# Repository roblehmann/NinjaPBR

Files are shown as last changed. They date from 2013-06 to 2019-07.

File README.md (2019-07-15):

# NinjaPBR - The Photobioreactor for Cyanobacteria and Microalgae

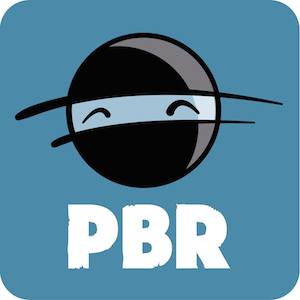
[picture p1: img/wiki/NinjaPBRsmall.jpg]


NinjaPBR is an opensource (GPLv3) photobioreactor implementation to study the growth of cyanobacteria and microalgae in liquid cultures. It allows the online measurement of the number of cells under various environmental conditions.

The firmware for the Arduino-based controller is located in this repository. The corresponding laser cutting templates and controller board Fritzing schematics are also provided here. The python-based graphical user interface can be found [here](https://github.com/roblehmann/pyNinjaPBR).

Want to learn more? See the [wiki](https://github.com/roblehmann/NinjaPBR/wiki).

## Motivation
One application of the NinjaPBR is the understanding of how cyanobacteria tell time. Some cyanobacterial strains predict the natural procession of light and dark phases during each day with an internal molecular clock consisting of the KaiA, B and C proteins. This clock evolved to accommodate the day length on earth of approximately 24h and can adapt to varying relative lengths of light and dark (LD) phases. The NinjaPBR allows the simulation of different day lengths, light and dark phase lengths, and also light brightness profiles over the subjective day. The observation of growth rates under extreme LD rhythms could indicate the limits of adaptibility of the circadian clock mechanism.

The central measured variable, the number of cells in the liquid culture, is measured as usual by the attenuation of incident light on its path through the solution (optical density, OD). In short, NinjaPBR

*  is an open-source, cost-effective, easy to assemble cultivation system
*  allows precise turbidity measurement using infrared light
*  can be easily extended to measure other parameters, e.g., O<sub>2</sub> and CO<sub>2</sub> in the off-gas
*  allows cultivation in batch, fed-batch, and chemostat mode
*  allows easy changes in illumination spectra by varying LEDs
*  is prepared for optional measurement of additional wavelengths to assess physiological parameters, e.g. pigment content

The NinjaPBR is designed to use a single controller box to control multiple Sample Pods, each hosting a separate culture vessel within a water bath. Accordingly, each pod requires a full set of sensors for each parameter, an illumination light source, and gas supply.

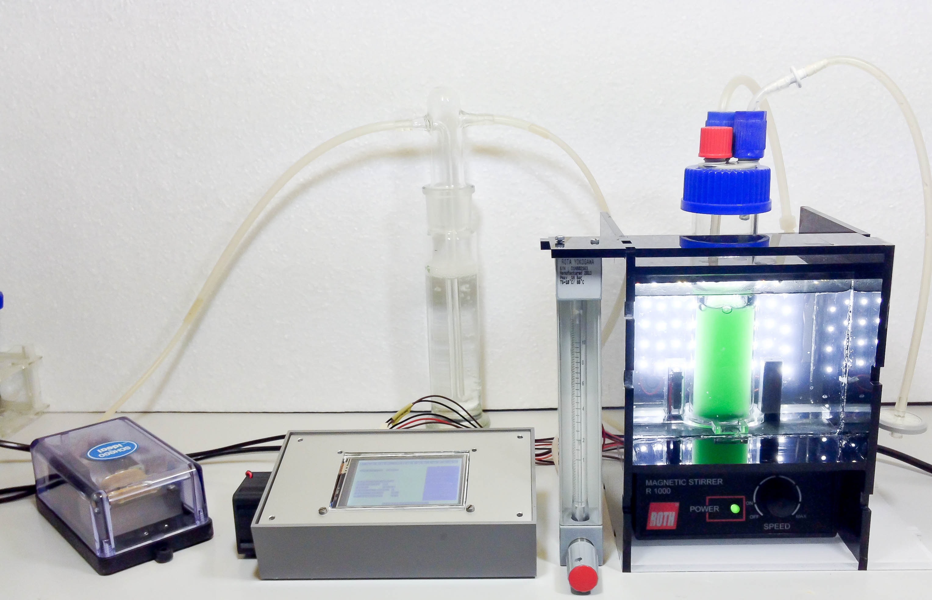
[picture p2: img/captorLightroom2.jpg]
Setup


*  Measure cell count via attenuation (OD, div. λ, calibration needed)
*  Temperature measured in water bath around vessel
*  Operation Modes: Batch, Fed Batch, Chemostat, (Turbidostat)
*  Compact – each Pod 205x140x150mm
*  Small sample volume < 120ml
*  Modular – 3 sample pods for 1 controller
*  Light programs for LED light source
*  Arduino-based controller for reactor management and data logging
*  Data transfer and control by computer GUI via USB

# Preliminary Experiments

### Batch Experiment with light/dark cycles
 The figure below shows the result of the following preliminary experiment:
 
*  Minimal reactor setup with Synechococcus sp. PCC 7002 in optimized media
*  Room temperature 24.5 °C, no temperature control
*  PFD 60 μmol m<sup>-2</sup>s<sup>-1</sup>
*  12/12h LD cycle using white LED light
*  Turbidity measured using 850nm wavelength
*  Reference measurement before experiment start with media-filled cuvette
*  sampling frequency F<sub>samp</sub> = 1/5 min<sup>-1</sup>
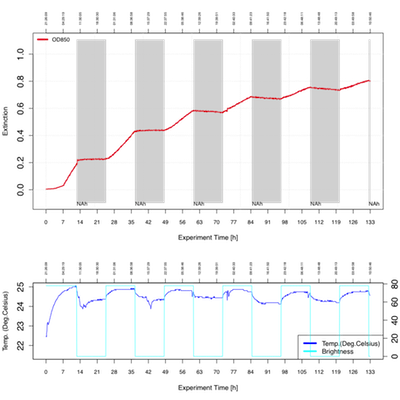
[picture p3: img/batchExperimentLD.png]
LD Batch Run


### Chemostat Experiment - Continuous dilution of culture with fresh media

*  Growth rate adjusts to dilution rate, yielding steady state in cell number
*  Experiment duration drastically extended up to months
*  Required extension of minimal setup:
	- Peristaltic pump attached to third reactor vessel port
	- Superfluous media due to dilution is removed via the off-gas vent via glass tube, which is placed at fixed height inside reactor vessel
* Experimental data with this setup are shown below
	-  Synechocystis sp. PCC 6803
	-  various LD rhythms
	-  Multiple wavelength OD measurement

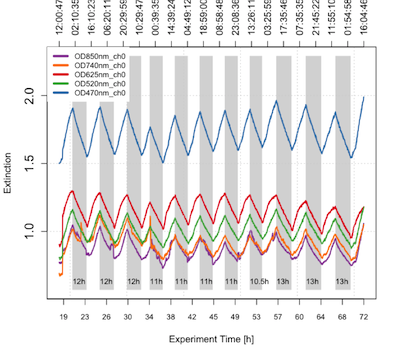
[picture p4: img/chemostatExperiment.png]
Chemostat Run


---
# Inspiration

There are already a range of great bioreactor and photobioreactor designs out there, here is a small selection. In addition, there are several other great instruments on github, such as the [NinjaPCR](https://github.com/hisashin/NinjaPCR) open source Thermocycler or a [plate reader](https://github.com/csbl/platereader).

### Synechocystis Physiological Parameters
A small part pf the extensive [contribution](http://2015.igem.org/Team:Amsterdam/Project/Phy_param/Synechocysytis) of team Amsterdam to the international Genetically Engineered Machine Competition iGEM 2015 consisted of the extension of a commercial PBR allowing its operation as turbidostat. This project involved the University of Amsterdam, the Free University of Amsterdam, the Swammerdam Institute for Life Sciences (SILS), and several other institutions.

### Biomonstaaar
The photobioreactor design called Biomonstaaar was developed as a part of the  SpaceGAMBIT program. It is documented on [SpaceGAMBIT](http://www.spacegambit.org/biomonstaaar-open-source-bioreactor/) and on [Instructables](http://www.instructables.com/id/Biomonstaaar/). The concept is to build an array of three photobioreactors, each of which is controlled by an Arduino. The resulting data are collected in a Raspberry Pi and then uploaded into the cloud.

### Bertha
The Bertha bioreactor project of the École polytechnique fédérale de Lausanne (EPFL) employs many useful technologies, such as ZigBee Bluetooth modules for wireless data transfer. The code as well as physical designs are provided on [github](https://github.com/Bioreactor/Code-Bioreactor).

---
# Instructions

### Pod Construction

* Sample pod built from 5mm thick PMMA sheet material
* 2D templates for laser cutting are provided as EPS files in the templates sub-folder
	- Order cutting online from e.g. www.formulor.de, www.ponoko.com
	- Or manufacture yourself (maker lab / own laser cutter)
*  Minimal number of required bonding connections
*  Standard 10mm polystyrene cuvettes additionally required for light source / detector housing
*  Adhesive required for assembly
*  Check the [Wiki](https://github.com/roblehmann/NinjaPBR/wiki/Pod-Assembly) for more details and images

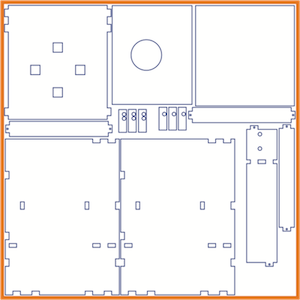
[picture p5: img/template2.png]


### Controller Based on Arduino

*  Arduino Mega + 3.2’’ touch screen with SD card slot
*  Breakout board for connection of periphery to Arduino provided as Fritzing sketch in the controller sub-folder
*  No expert knowledge in electronics required
*  Parts readily available 
*  Basic breakout board with 12V LED driver for all sample pods, and max. 2 emitter types on stripboard shown below
*  Controller puts out 12V for emitter, requiring separate driver ICs or current limiting resistors for each LED connection

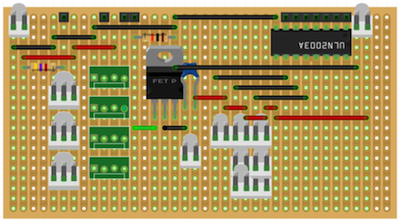
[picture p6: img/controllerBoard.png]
Controller Board


### Measurement of Cell Density

*  Standard attenuation measurement, comparable to benchtop spectrophotometer
*  Through culture vessel, yielding 40mm optical path
*  850nm high power Led with constant current source for highly constant output
*  No lenses required
*  Calibration curve of extinction to cell number required
*  Extension prepared to use side-scattering to increase linear range and decrease dependency on cell morphology
*  [Wiki](https://github.com/roblehmann/NinjaPBR/wiki/Measuring-Cell-Number) for more

### Python GUI

*  Download and display data from controller
*  Online display when continuously connected
*  Data logging
*  Up- / download scripted light programs
*  Scheduled reactor mode change (planned experiment start)
*  Easy GUI customization using wxGlade
*  [The Repository](https://github.com/roblehmann/pyNinjaPBR)

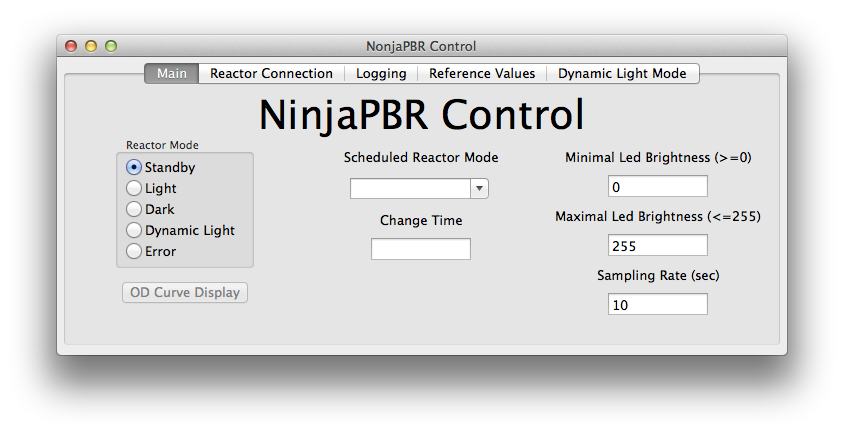
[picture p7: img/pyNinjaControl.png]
Frist Experiment


---
# Contribute to NinjaPBR!

Im looking for people who are interested in helping develop the NinjaPBR or apply it.

---
# Author
[Robert Lehmann](https://github.com/roblehmann)

Check out [Celldeg.com](http://celldeg.com/) if you are interested in ultra-high density cultivation of cyanobacteria

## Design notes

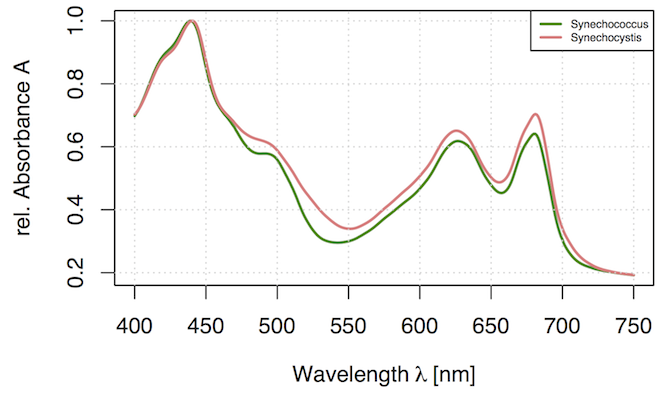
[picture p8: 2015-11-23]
img/wiki/od/cyano_absorbance_spectra.png

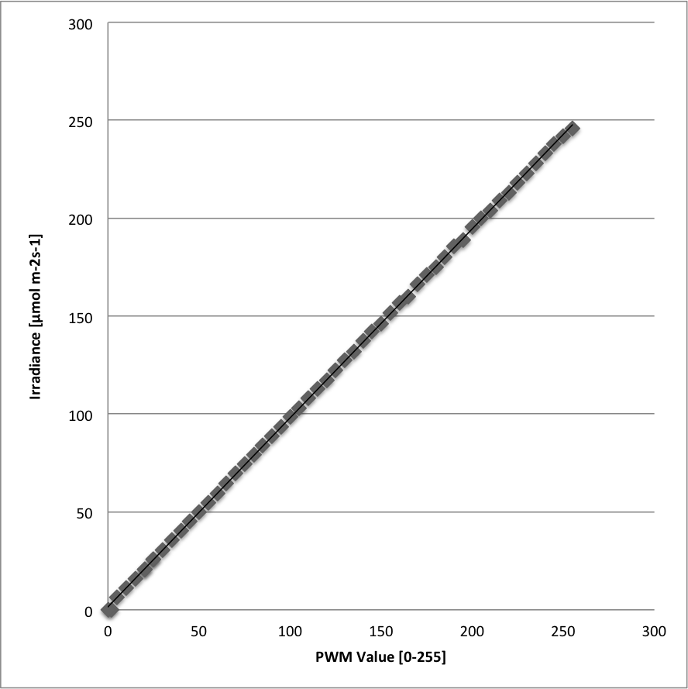
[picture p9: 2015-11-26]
img/wiki/controller/lightIntensity.png

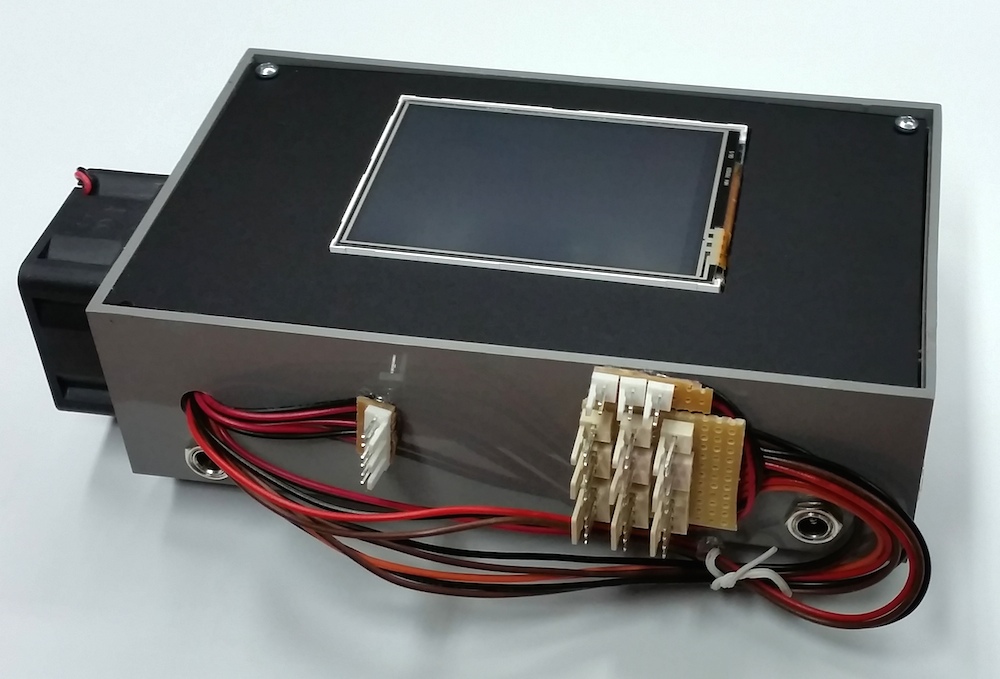
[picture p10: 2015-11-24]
img/wiki/controller/controller3.jpg

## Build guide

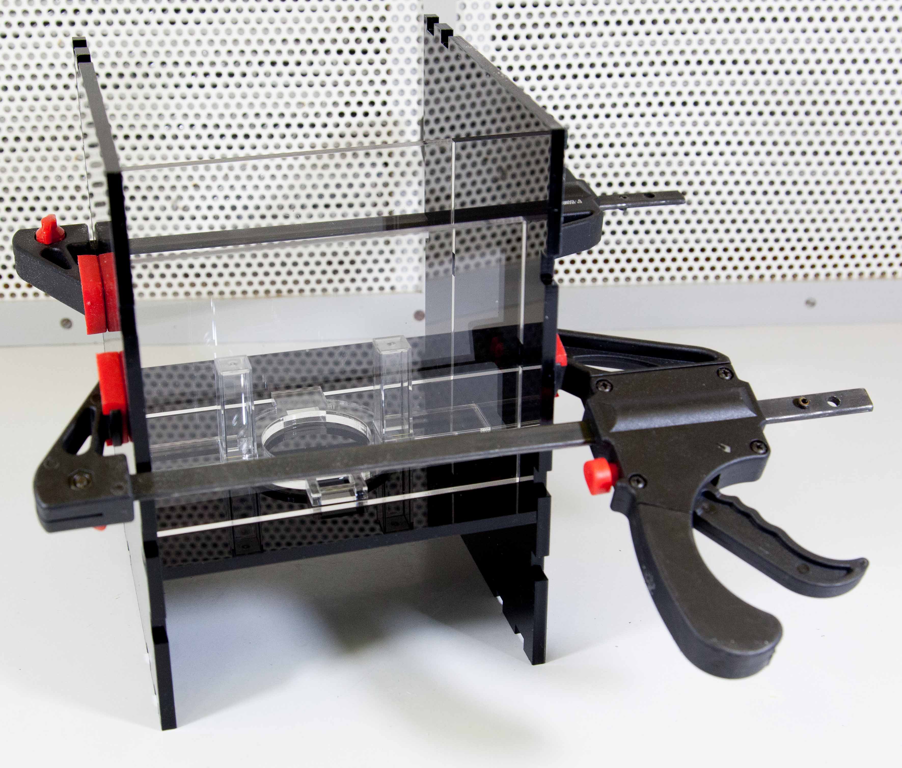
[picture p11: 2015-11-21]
img/wiki/assembly/step5.jpg

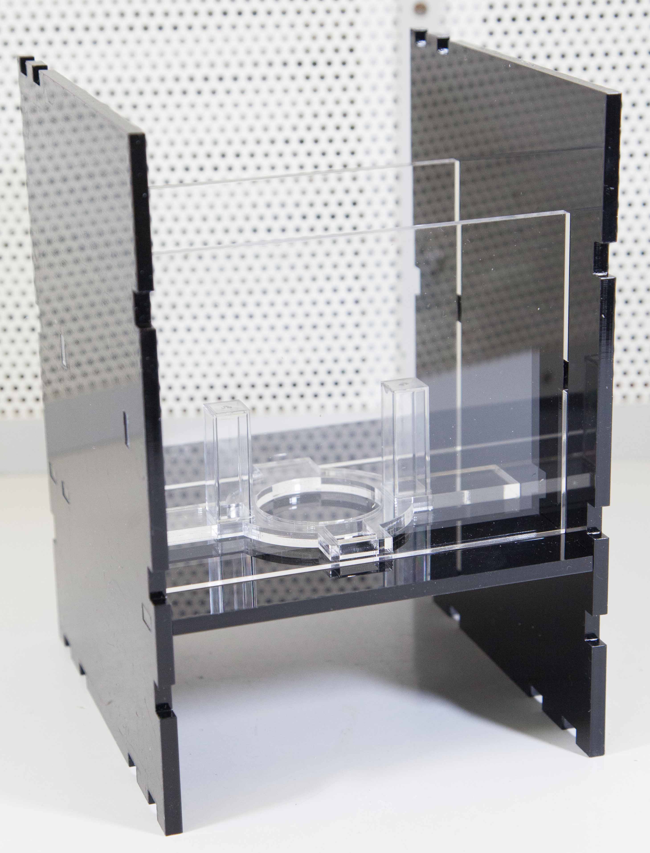
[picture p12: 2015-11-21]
img/wiki/assembly/step6.jpg

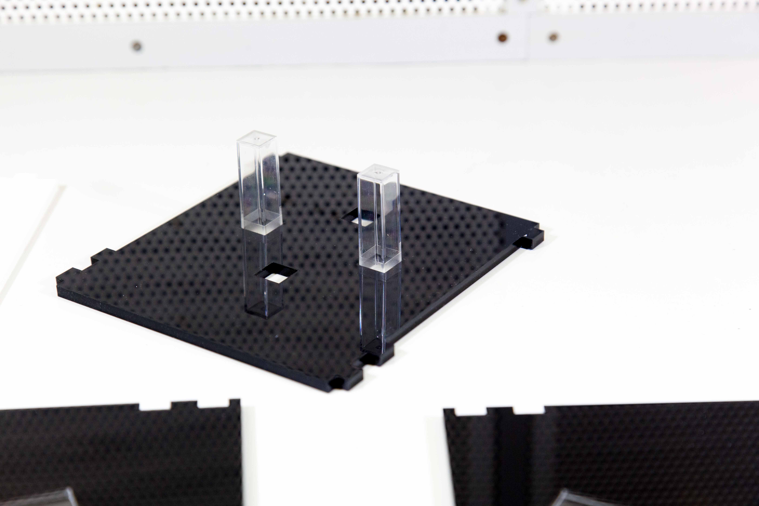
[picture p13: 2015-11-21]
img/wiki/assembly/step1a.jpg

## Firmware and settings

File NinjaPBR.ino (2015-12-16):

/*-------------------------
// NinjaPBR
// Arduino-based Photobioreactor for the cultivation of cyanobacteria and microalgae
//
// Author: r.lehmann@biologie.hu-berlin.de
-------------------------*/

#include <OneWire.h>
#include <DallasTemperature.h>
#include <Timer.h>
#include <Wire.h>
#include <TSL2561_mod.h>
#include <DS3232RTC.h>
#include <Time.h>
#include <UTFT.h>
#include <UTouch.h>
#include <UTFT_Buttons.h>
#include <SPI.h>
#include <SdFat.h>

//----------CONSTANTS-GLOBAL--------- //
#define BIOREACTOR_STANDBY_MODE   0   // nothing on, nothing measured
#define BIOREACTOR_LIGHT_MODE     1   // light const. at full brightness, od/temp. measured
#define BIOREACTOR_DARK_MODE      2   // light off, od/temp. measured
#define BIOREACTOR_DYNAMIC_MODE   3   // light varies according to uploaded dynamic profile, od/temp. measured
#define BIOREACTOR_ERROR_MODE     4   // something went wrong,switch off everything

//----------CONSTANTS-LIGHT--------- //
//#define  ledPin     13  // LED panel connected to digital pin 3
const int lightPins[] = {11,12,13};

#define MAX_LIGHT     0   // set illumination to specified max
#define MIN_LIGHT     1   // set illumination to specified min

//----------CONSTANTS- EMITTER --------- //
#define numLeds 1     // number of emitters with different wavelength
// number of culture chambers with individual OD sensors
// needs to match the number of OD sensor pins per type
const int ledPins[] = {8, 10};

//----------Number of Pods --------- //
#define numChambers 3

//----------CONSTANTS-GAS--------- //
#define  airValvePin 9
//----------CONSTANTS-MEDIUM--------- //
#define  mediumPumpPin 6

// marks default state of timer
#define timerNotSet -1

//----------CONSTANTS-TEMPERATURE--------- //
#define TEMPERATURE_SENSOR_PIN  19   // culture temperature

//----------TIMER DECLARATION--------- //
Timer t;

//----------GLOBAL VARIABLES--------- //
//global variables used by functions and are set by GUI
byte BIOREACTOR_MODE = BIOREACTOR_STANDBY_MODE;
byte bioreactorAncientMode = BIOREACTOR_STANDBY_MODE;

// LIGHT REGULATION //
byte minLightBrightness[3] = {0};
byte maxLightBrightness[3] = {255, 255, 255};

byte lightBrightness[3] = {0};       // holds brightness of LED panel in range 0-255 (0=off)

// Light profile //
const int      lightProfileLength = 200;
byte           brightnessValue[3][lightProfileLength];
unsigned long  brightnessDuration[3][lightProfileLength];
int            lightProfileIdx[3] = {0}; // indicates the current position in the light profile 

// Turbidostat Mode //
// if active, reactor checks of optical density exceeds "upperOdThr". if so, a
// series of dilution steps of length dilutionDuration are issued, until the OD
// is found below "lowerOdThr"
boolean  inTurbidostat    = false;   // is turbidostat mode is active
boolean  inDilution       = false;   // is turbidostat mode is active
int      dilutionDuration = 1;       // how long the medium pump should run to dilute one step (sec)
float    upperOdThr       = 1;       // when to start diluting
float    lowerOdThr       = .8;      // when to stop diluting

// OD MEASUREMENTS //
// array storing the resulting OD values for logging
// column 5 stores background values, column 0-4 the background-corrected OD values
float odValues[numChambers][ 6 ] = {0};

//reference values for OD calculation
// column 5 stores background values, column 0-4 the background-corrected reference intensity values
float refValues[numChambers][ 6 ] = {65535, 65535, 65535, 65535, 65535, 65535};

// emitter-specific brightness value. 
// adjust this value to optimize for individual geometry
// set to 100 for integration time 2 and sfh4550
float emitterBrightness[ 5 ] = {100,162,255,255,255};

// state flag, determining whether to measure reference value for OD calculation or OD values
boolean readReferenceValues = false;
//flag indicating if reference values were read already
String referenceValuesDone = "";

// AIR PUMP REGULATION //
boolean airPumpState;

// how often to measure od/temp
unsigned long sensorSamplingTime = 5L; //seconds

// store timer IDs, to be able to remove them when the BIOREACTOR_MODE or the sample timer change
int lightChangeTimerID[] = {-1, -1, -1};
int sensorReadTimerID = -1;

float temperatureInLiquid[3] = {0, 0, 0};

String inputString = "";         // a string to hold incoming data
boolean stringComplete = false;  // whether the string is complete
// for logging and communication
const char* sep = ",";
String sepT = "/";  //separator char for logging and display
String curr_t; // holds time stamp of current sample

// SD logging vars
#define FILE_BASE_NAME "NPLog"
char fileName[13] = FILE_BASE_NAME "00.csv";
bool SDavail = false;
bool SDlogging = false;
//send handshakes until connected
bool serialConnected = false;

const int line_buffer_size = 140;
char buffer[line_buffer_size];
String paramName;
float  paramValue;


//----------------------------- //
//----------setting up--------- //
//----------------------------- //
void setup()  {
  // for serial input message
  inputString.reserve(50);

  // initialize reactor mode and functions
  bioreactorAncientMode = BIOREACTOR_STANDBY_MODE;
  BIOREACTOR_MODE = BIOREACTOR_STANDBY_MODE;
  
  initSerial();
  lightSetup();
  temperatureSetup();
  odSetup();
  pumpSetup();
  loggingSetup();
  setupDisplay();
  // update all the sensor data for once before doing the first log
  updateSensorLogValues();
} 

//----------------------------- //
//----------loop--------- //
//----------------------------- //
void loop()  { 
  // update the timer
  t.update();
  //check if mode change seleceted via display
  check_settings_selected();
  // read new configuration from Serial
  checkSerialMessage();
  // check if reactor mode changed and make changes effective
  checkChangedReactorMode();
}


void checkChangedReactorMode() 
{
  // check if reactor mode changed, and put changes into effect
  if(bioreactorAncientMode != BIOREACTOR_MODE)  
  {
    bioreactorAncientMode = BIOREACTOR_MODE;
    switch(BIOREACTOR_MODE)
    {
    case BIOREACTOR_STANDBY_MODE: 
      { 
        // to go into standby, need to switch off light, remove timers for day phase/light change
        // open pinch valves - permant close-state causes damage
        startAirPump();
        // switch off light, remove timers
        stopSensorReadTimer();
        setMaxMinLight(MIN_LIGHT);
        break;
      }
    case BIOREACTOR_DYNAMIC_MODE:
      {
        // activate air pump 
        startAirPump();
        // ------------ Adding timed actions ----------
        startSensorReadTimer();
        startDynamicLightTimers();
        break;
      }
    case BIOREACTOR_LIGHT_MODE:
      {
        startAirPump();
        setMaxMinLight(MAX_LIGHT);
        startSensorReadTimer();
        Serial.println(F("Set Light Mode"));
        break;
      }
    case BIOREACTOR_DARK_MODE:  
      {
        startAirPump();
        setMaxMinLight(MIN_LIGHT);
        startSensorReadTimer();
        break;
      }
    case BIOREACTOR_ERROR_MODE:
      {
        stopAirPump();
        setMaxMinLight(MIN_LIGHT);
        stopSensorReadTimer();
        break;
      }
    default:
      BIOREACTOR_MODE = BIOREACTOR_ERROR_MODE;
      startAirPump();
      setMaxMinLight(MIN_LIGHT);
      stopSensorReadTimer();
      break;
    }
    sendMode();
    showData();
  }
}

/*
method is called when message comes via usb. incoming messages
 are collected until message terminating character is see, then 
 digestion is triggered
 */
void serialEvent() {
  while (Serial.available()) {
    // read new byte
    char inChar = (char) Serial.read(); 
    // add it to the inputString:
    inputString += inChar;
    // character "#" marks end of message, if seen trigger digestion
    if (inChar == '#') 
      stringComplete = true;
    else // wait for serial buffer, otherwise get overflows and thus dropped messages from computer 
      delay(20);
  }
}


void checkSerialMessage() {
  if (stringComplete) {
    if (inputString != "")       // change setup according to message
      digestMessage();
    // clear the string:
    inputString = "";
    stringComplete = false;
  }
}

/*-------------------------------- 
 method takes message from controlling computer and parses it, assigning the 
 command value to the corresponding variable. 
 messages structure:
 parameterName:parameterValue#
 --------------------------------*/
void digestMessage() 
{
  inputString.toCharArray(buffer, line_buffer_size); 
  paramName = strtok(buffer,sep);
  paramValue = atof(strtok(NULL,sep));

  if(paramName == F("md")) // which reactor program to use
  {
    BIOREACTOR_MODE = paramValue;
    prepareBoxDisplay();
  }
  else if(paramName == F("sst")) // how often to sample
  {
    sensorSamplingTime = paramValue;
    if(sensorReadTimerID != timerNotSet) // if sampling is currently active, make new frequency active
    {
      stopSensorReadTimer(); // restart sampling timer
      startSensorReadTimer(); // standby mode and reinit reactor mode
    }
  }
  else if(paramName == F("malb")) // maximal brightness of the LED panel
  {
    maxLightBrightness[0] = paramValue;
    for(int i=1; i < numChambers; i++)
    {
      maxLightBrightness[i] =  atoi(strtok(NULL,sep));
    }
    for(int i=0; i < numChambers; i++)
      lightUpdate(i);
  }
  else if(paramName == F("milb")) // minimal brightness of the LED panel
  {
    
    minLightBrightness[0] = paramValue;
    for(int i=1; i < numChambers; i++)
    {
      minLightBrightness[i] = atoi(strtok(NULL,sep));
    }
    for(int i=0; i < numChambers; i++)
      lightUpdate(i);
  }
  else if(paramName == F("mre")) // measure reference values for OD calculation
  {
    // set flag to read reference values (without OD calculation)
    readReferenceValues = true;
    odUpdateStart();
  }
  else if(paramName == F("bp")) // receive brightness profile values
  {
    if( paramValue >= 0 && paramValue < numChambers) // check if valid chamber is addressed
    {
      // first value is the channel, second the index, third is the brightness (0-255), fourth is the duration in seconds
      int idx = atoi(strtok(NULL,sep));
      if(idx >= 0 && idx < lightProfileLength)
      {
        brightnessValue[int(paramValue)][idx]     = atoi(strtok(NULL,sep));
        brightnessDuration[int(paramValue)][idx]  = atol(strtok(NULL,sep));
        Serial.print('MSG,');
        Serial.print((String) brightnessValue[int(paramValue)][idx] );
        Serial.print(' ');
        Serial.print((String)brightnessDuration[int(paramValue)][idx]);
        Serial.print(' ');
        Serial.println(idx);
      }
      else 
      {
        sendError(F("invalid light profile idx"));
      }
    } 
    else {
      sendError(F("invalid channel"));
    }
  }  
  else if(paramName == F("it")) // set turbidostat mode. if paramValue==1, activate, otherwise deactivate
  {
    inTurbidostat = (paramValue==1);
  }
  else if(paramName == F("dd")) // set length of dilution (how long the medium pump runs in seconds)
  {
    dilutionDuration = paramValue;
  }
  else if(paramName == F("uot")) // OD when to start dilution
  {
    upperOdThr = paramValue;
  }
  else if(paramName == F("lot")) // OD when to stop dilution
  {
    lowerOdThr = paramValue;
  }
  else if(paramName == F("sbp")) // receive brightness profile values
  {
    sendLightProfile(paramValue);
  }
  else if(paramName == F("hi")) // acknowledge serial connect
  {
    //set back flag to stop sending handshakes again
    serialConnected = true;
    StopSendingHandshake();
  }
  else if(paramName == F("bye")) // acknowledge serial disconnect
  {
    //set back flag to start sending handshakes again
    serialConnected = false;
    StartSendingHandshake();
  }
  else if(paramName == F("log")) // request to send all log data from current file
  {
    sendLogData();
  }
  else
  {
    sendError("unknown message: " + paramName);
  }
  saveParameters();
}

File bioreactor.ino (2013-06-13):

#include <OneWire.h>
#include <DallasTemperature.h>
#include <Timer.h>

//----------CONSTANTS-GLOBAL--------- //
#define BIOREACTOR_STANDBY_MODE   1   // nothing on, nothing measured
#define BIOREACTOR_LIGHT_MODE     2   // light const. at full brightness, od/temp. measured
#define BIOREACTOR_DARK_MODE      3   // light off, od/temp. measured
#define BIOREACTOR_CIRCADIAN_MODE 4   // light varies circadian, od/temp. measured
#define BIOREACTOR_ERROR_MODE     5  // somewthing went wrong,switch off everything

//const char* MODE_NAMES[] = {
//  "BIOREACTOR_STANDBY_MODE","BIOREACTOR_LIGHT_MODE","BIOREACTOR_DARK_MODE",
//  "BIOREACTOR_CIRCADIAN_MODE","BIOREACTOR_ERROR_MODE"};
//----------CONSTANTS-LIGHT--------- //
#define  ledPin     3  // LED panel connected to digital pin 3
//----------CONSTANTS-GAS--------- //
#define  pumpPin    4  // Pump connected to digital pin 4
//----------CONSTANTS-OD--------- //
#define  irPin      8  //IR-Emitter diode
#define  odPin      A0  // OD detector diode
#define  odPin2      A1  // OD detector diode
#define  odPin3      A2  // OD detector diode
//----------CONSTANTS-TEMPERATURE--------- //
#define PIN_TEMPERATURE_SENSOR_IN_LIQUID  2   // temperature on culure bottle

//----------CONSTANTS-LIGHT REGULATION ------- //
// status variable marking circadian phase
#define PHASE_MORNING 1 // defined as DL transition
#define PHASE_DAY 2 // defined as max. light intensity
#define PHASE_EVENING 3 // defined as LD transition
#define PHASE_NIGHT   4 // defined as min. light intensity
#define PHASE_NONE    5 // if no circadian program is used

//const String PHASE_NAMES[] = {
//  "PHASE_MORNING","PHASE_EVENING","PHASE_NIGHT","PHASE_NONE"};

//----------TIMER DECLARATION--------- //
Timer t;

//----------GLOBAL VARIABLES--------- //
//global variables used by functions and are set by WebUI
boolean DEBUG = true;
int BIOREACTOR_MODE = BIOREACTOR_STANDBY_MODE;
int bioreactorAncientMode = BIOREACTOR_STANDBY_MODE;

// LIGHT REGULATION //
int minLightBrightness = 0;
int maxLightBrightness = 255;
// 13,5cm Bottle-Panel and full brightness with 22V = 60 micromol
//0: 1.32
//10: 6.08
//20: 8.38
//30: 10.69
//40: 12.99
//50: 15.3
//60: 17.59
//70: 19.88
//80: 22.14
//90: 24.44
//100: 26.73
//110: 29.01
//120: 31.3
//130: 33.6
//140: 35.9
//150: 38.18
//160: 40.45
//170: 42.73
//180: 44.98
//190: 47.22
//200: 49.46
//210: 51.71
//220:53.92
//230:56.04
//240:57.94
//250:59.4

int lightBrightness = 0;       // holds brightness of LED panel in range 0-255 (0=off)
int lightChangeStep = 25;       // how strong the light intensity changes between two consecutive steps
double lightChangeStepLength = 1; // how long should a step to the next light level be  /seconds
int dayPhase = PHASE_NONE;     // holds whether it is MORNING, EVENING, or NIGHT

unsigned long PHASE_MORNING_DURATION  = 10; // defined as DL transition /seconds
unsigned long PHASE_DAY_DURATION      = 1; // defined as max. light intensity /seconds
unsigned long PHASE_EVENING_DURATION  = 10; // defined as LD transition /seconds
unsigned long PHASE_NIGHT_DURATION    = 11; // defined as min. light intensity /seconds

// air pump regulation 
boolean airPumpState;

// how often to measure od/temp
int sensorSamplingTime = 2; //seconds

// store timer IDs, to be able to remove them when the BIOREACTOR_MODE or the light-change-params change
int lightChangeTimerID = -1;
int sensorReadTimerID = -1;

String inputString = "";         // a string to hold incoming data
boolean stringComplete = false;  // whether the string is complete

//----------------------------- //
//----------setting up--------- //
//----------------------------- //
void setup()  {
  // for serial input message
  inputString.reserve(50);

  // init serial for OD
  Serial.begin(9600);
  lightSetup();
  temperatureSetup();
  odSetup();
  pumpSetup();
  // update all the sensor data for once before doing the first log
  updateSensorLogValues();

  bioreactorAncientMode = BIOREACTOR_STANDBY_MODE;
  BIOREACTOR_MODE = BIOREACTOR_STANDBY_MODE;
} 

//----------------------------- //
//----------loop--------- //
//----------------------------- //
void loop()  { 
  // update the timer
  t.update();
  // read new configuration from Serial
  checkSerialMessage();
  // check if reactor mode changed and make changes effective
  checkChangedReactorMode();
}


void checkChangedReactorMode () 
{
  // check if reactor mode changed, and put changes into effect
  if(bioreactorAncientMode != BIOREACTOR_MODE)  
  {
    bioreactorAncientMode = BIOREACTOR_MODE;
    switch(BIOREACTOR_MODE)
    {
    case BIOREACTOR_STANDBY_MODE: 
      { 
        // to go into standby, need to switch off light, remove timers for day phase/light change
        if(DEBUG) Serial.println("standby mode");
        // deactivate air pump 
        stopAirPump();
        // switch off light, remove timers
        stopSensorReadTimer();
        lightOff();
        break;
      }
    case BIOREACTOR_CIRCADIAN_MODE:
      {
        if(DEBUG) Serial.println("circadian mode");
        // activate air pump 
        startAirPump() ;
        // ------------ Adding timed actions ----------
        startSensorReadTimer();
        startCircadianLightTimers();
        break;
      }
    case BIOREACTOR_LIGHT_MODE:
      {
        if(DEBUG) Serial.println("light mode");
        startAirPump() ;
        lightOn();
        startSensorReadTimer();
        break;
      }
    case BIOREACTOR_DARK_MODE:  
      {
        if(DEBUG) Serial.println("dark mode");
        startAirPump() ;
        lightOff();
        startSensorReadTimer();
        break;
      }
    case BIOREACTOR_ERROR_MODE:
      {
        if(DEBUG) Serial.println("ERROR mode");
        stopAirPump() ;
        lightOff();
        stopSensorReadTimer();
        break;
      }
    default:
      Serial.println("unknown->ERROR mode");
      BIOREACTOR_MODE = BIOREACTOR_ERROR_MODE;
      stopAirPump() ;
      lightOff();
      stopSensorReadTimer();
      break;
    }
    loggingEvent();
  }
}

/*
  SerialEvent occurs whenever a new data comes in the
 hardware serial RX.  This routine is run between each
 time loop() runs, so using delay inside loop can delay
 response.  Multiple bytes of data may be available.
 */
void serialEvent() {
  while (Serial.available()) {
    // get the new byte:
    char inChar = (char)Serial.read(); 
    // add it to the inputString:
    inputString += inChar;
    // if the incoming character is a newline, set a flag
    // so the main loop can do something about it:
    if (inChar == '#') {
      stringComplete = true;
    }
  }
}


void checkSerialMessage() {
  if (stringComplete) {
    if (inputString != "") 
    {
      if(DEBUG) Serial.println(inputString);
      // change setup according to message
      digestMessage();
    }
    // clear the string:
    inputString = "";
    stringComplete = false;
  }
}
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

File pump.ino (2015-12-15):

/*-------------------------
management of gas supply in 
sample pods
-------------------------*/

void pumpSetup()
{
   // setup air pump
  pinMode(airValvePin, OUTPUT);
  startAirPump();
  
  // setup medium pump
  pinMode(mediumPumpPin, OUTPUT);
  stopMediumPump();
}

//---------   air supply part ---------//
void startAirPump()
{
  airPumpState = HIGH;
  // air by pinch valve control
  digitalWrite(airValvePin, LOW);
}

void stopAirPump() 
{
  // air by pump on/off control
  airPumpState = LOW;
  // air by pinch valv control
  digitalWrite(airValvePin, HIGH);
}

//---------   medium supply part for turbidostat ---------//
// performs dilution
void doDilution(int duration)
{
  startMediumPump();
  t.after(duration * 1000L, stopMediumPump);
}
// starts dilution 
void startMediumPump()
{
  digitalWrite(mediumPumpPin, HIGH);
}
// stops dilution
void stopMediumPump() 
{
  digitalWrite(mediumPumpPin, LOW);
}

// checks if turbidostat mode is activated. if so, checks if upper OD is
// exceeded, then starts dilution process. if already in dilution process, checks if
// OD is below lower threshold, then stops.
void turbidityUpdate()
{
  // TODO: could combine starting and continuing condition. but for clarity...
  if(!inTurbidostat) return; // turbidostat not active
  // TS active, and dilution not started and upper OD at 750nm (sensor2) is exceeded -> start dilution process
  if(!inDilution & (odValues[1][1] > upperOdThr) )
  {
    inDilution = true;
    doDilution(dilutionDuration);
  }
  // TS active, dilution started and lower OD at 750nm (sensor2) is exceeded -> continue dilution process
  else if(inDilution & (odValues[1][1] > lowerOdThr) )
  {
    doDilution(dilutionDuration);
  }
  // TS active, dilution started and OD is below lower thr -> stop dilution process
  else if(inDilution & (odValues[1][1] <= lowerOdThr) )
  {
    inDilution = false;
  }
}

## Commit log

2013-06-17 fixed bug with timer length variable overflow and phase advancing
    [captor.ino, global.ino, light.ino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]
2013-06-23 organize air pump code, change to pwm mode to adjust pump speed
2013-06-23 extended readme. prepared addition of pinch valve
2014-01-08 change background calculation to allow for sensors which either increase or decrease with increasing light.
2014-01-08 switch to magnetic pinch air valve
2014-01-09 added support for multiple culture chambers/OD sensors.
2014-01-10 switched to magnetic air pinch valve
2014-01-10 fixed switched pump states
    [pump.ino]
2014-01-16 storing sensor read delay in variable
2014-02-12 started developing version with only one sensor. changed sensor sampling strategy, using timers to start measuring and then come back later to collect results as preparation for the TSL2561
2014-02-16 move to a single TSL2561 sensor
2014-02-20 removed ir correction for now
    [opticalDensity.ino]
2015-11-19 added controller board, cutting template, and updated the readme
    [NinjaBoard.fzz]
2015-11-26 new brightness plot with 24V
2015-12-15 switched to fixed temperature sensor addresses to be able to assign temps. to sample pods
    [temperature.ino]
2015-12-15 leave air vales open upon startup to avoid overheating due to extended closed periods
    [pump.ino]
2015-12-16 fixed reading reference values from SD card
    [logging.ino]
2015-12-16 leaving air valves open in init.fixed log reading in case of 3 sample pods (larger IO buffer). bit of comment clean up.
    [NinjaPBR.ino, opticalDensity.ino]
